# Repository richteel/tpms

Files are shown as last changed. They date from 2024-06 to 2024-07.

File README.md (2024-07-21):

# Raspberry Pi Pico Tire/Tyre Pressure Monitoring System (TPMS) Monitor

The Tire light was illuminated on the dash of my 2007 Prius. I ran around checking the air pressure in the tires. Found that a few were perhaps a little low, but not enough to cause the dash light to be lit. I then assumed that one or more of the TPMS sensors had a dead battery, but how can I know for certain? I took it to the garage and found that yes, one was dead and one had a low battery. The garage replaced them both. This got me to look and see if anyone had built a TPMS display to show the pressure and temperature of each tire.

After searching a bit, I came across an article on <a href="https://www.hackster.io/jsmsolns/arduino-tpms-tyre-pressure-display-b6e544" target="_blank">hackster.io</a> titled, "Arduino TPMS Tyre Pressure Display". It was just the thing I was looking for. I wanted to use a Raspberry Pi Pico as I have a few of them here, but the code posted does not support the RP2040 micro-controller used in the Raspberry Pi Pico. I was able to modify the code to work with the RP2040. My code will be available on GitHub at <a href="https://github.com/richteel/tpms" target="_blank">https://github.com/richteel/tpms</a> and some posts available at <a href="https://teelsys.com/" target="_blank">https://teelsys.com/</a>.

Newer cars have the details of the TPMS built in so it is not necessary to guess, but my older Prius does not. With this project, I will be able to monitor the health of my tires and when on a road trip and the dash light comes on, I don't need to panic and pull over to see if it is a major issue, that needs to be resolved right away, or if it is something that I can wait until I get to my destination.

## Items used in my build ##

- <a href="https://www.adafruit.com/product/4883" target="_blank">Raspberry Pi Pico (Pimoroni Pico Lipo) NOTE: Used Earle Philhower's core</a>
- <a href="https://www.adafruit.com/product/358" target="_blank">Adafruit 1.8" Color TFT LCD display with MicroSD Card Breakout - ST7735R</a>
- <a href="https://www.amazon.com/gp/product/B0C8RRG88V/ref=ppx_yo_dt_b_asin_title_o04_s00?ie=UTF8&psc=1" target="_blank">CC1101 Radio Frequency Transceiver Module</a>
- <a href="https://www.adafruit.com/product/160" target="_blank">Buzzer</a>
- 1 10 Ohm Resistor
- 2 150 Ohm Resistors
- <a href="https://www.pcbway.com/project/shareproject/Raspberry_Pi_Pico_Tire_Tyre_Pressure_Monitoring_System_TPMS_48b6424e.html" target="_blank">PCB from PCBWay</a>

## Code Notes ##

### TPMS_Monitor ###
The code in the TPMS_Monitor folder is the original code modified to work with the Raspberry Pi Pico code using Earle Philhower's core. This code is hard coded for US 315 MHz and Toyota PMV-107J sensors.

### TPMS_Monitor2 ###
Currently a work in progress to allow configuration to any supported sensor configuration. This code is not ready for use. Code changes will be checked in occasionally as code is updated. An Excel workbook, TPMS_Monitor2.xlsx, has been added with some analysis to help with the development of the modified version.

<hr />

I hope you enjoy this project and have success building it.

<a href="https://www.pcbway.com/project/shareproject/Raspberry_Pi_Pico_Tire_Tyre_Pressure_Monitoring_System_TPMS_48b6424e.html">PCB from PCBWay</a>

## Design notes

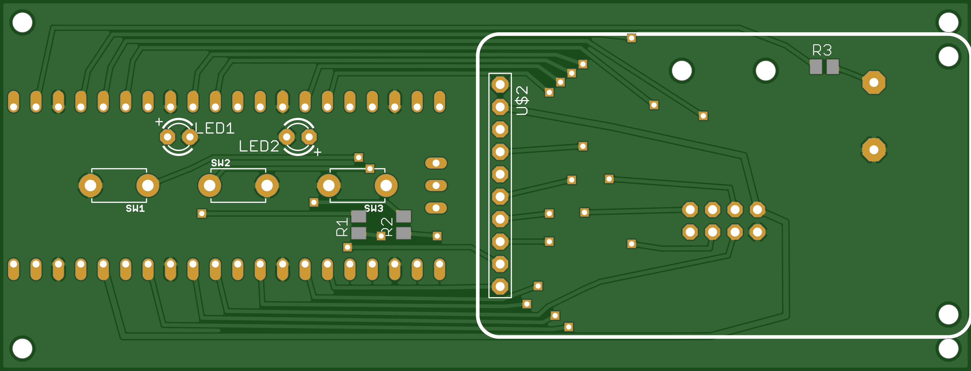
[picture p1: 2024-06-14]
PCB/top.png

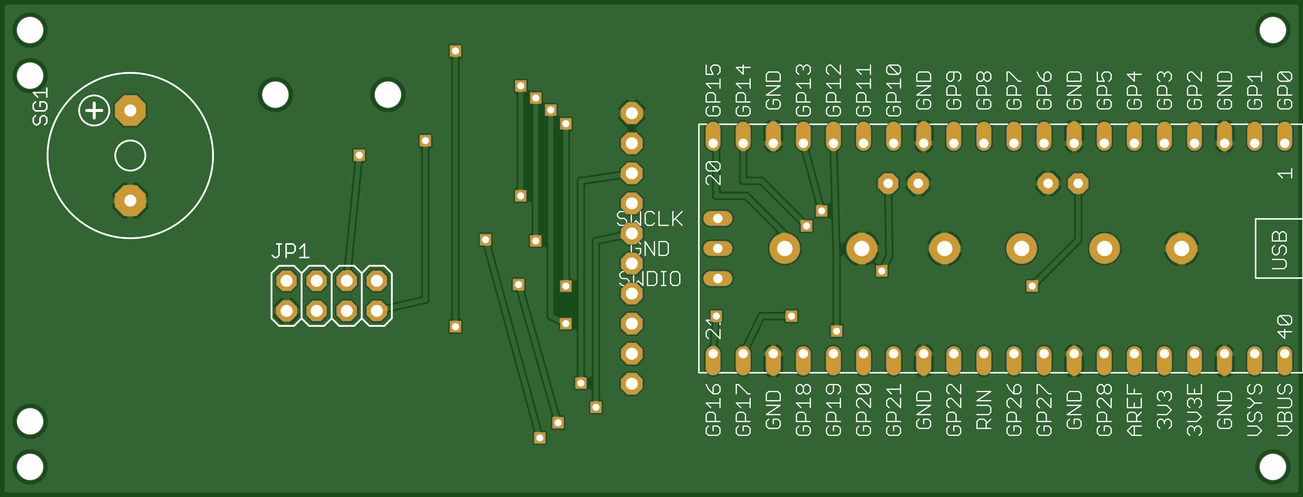
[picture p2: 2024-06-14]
PCB/bottom.png

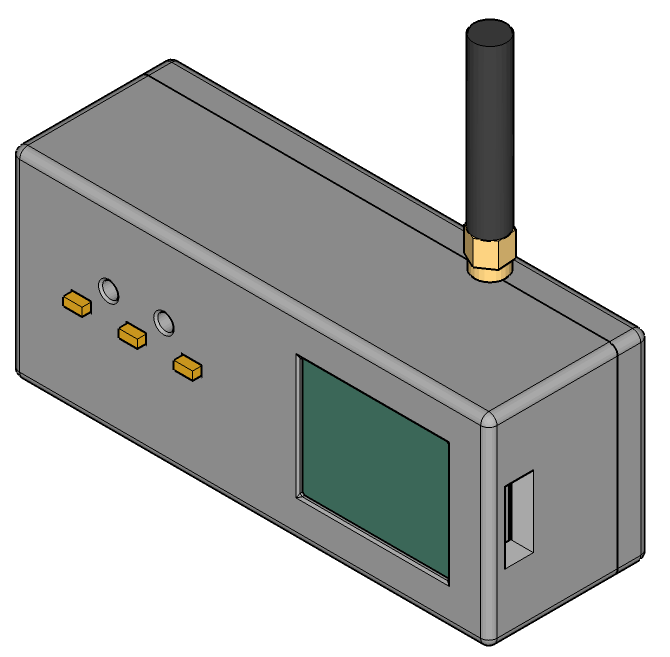
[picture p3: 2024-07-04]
Case/TPMS Case.png

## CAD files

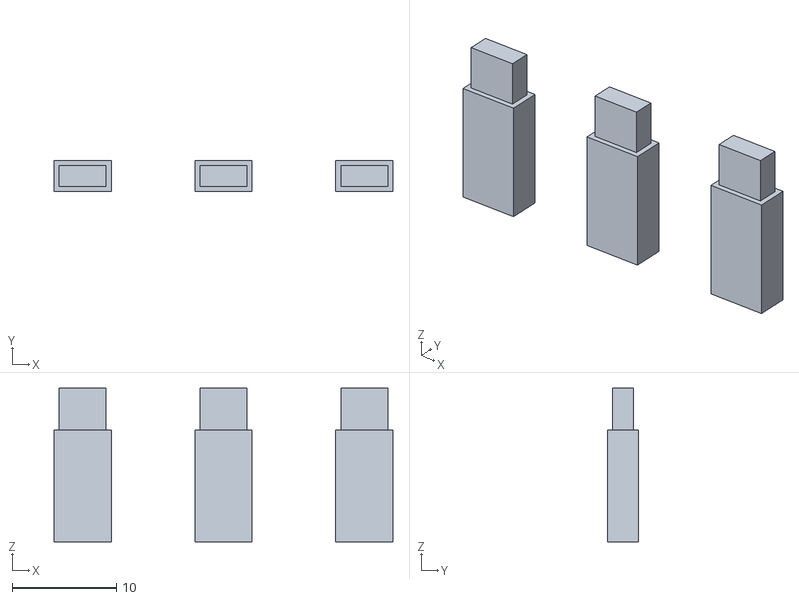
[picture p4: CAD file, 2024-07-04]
Case/TPMS Case Buttons.stl
32.5 x 3.00 x 14.7

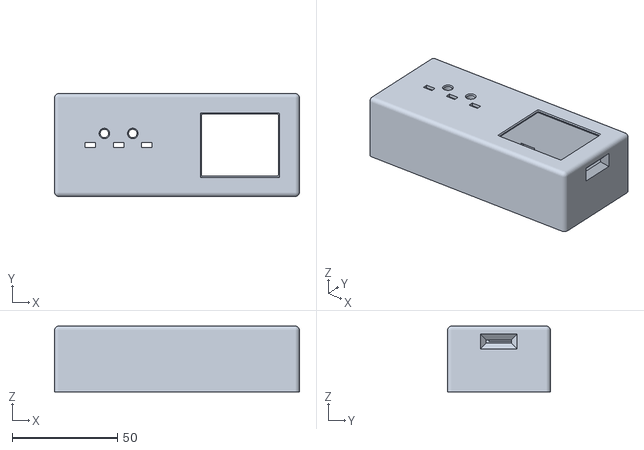
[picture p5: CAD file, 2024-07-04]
Case/TPMS Case Front.stl
116.6 x 49.0 x 31.4

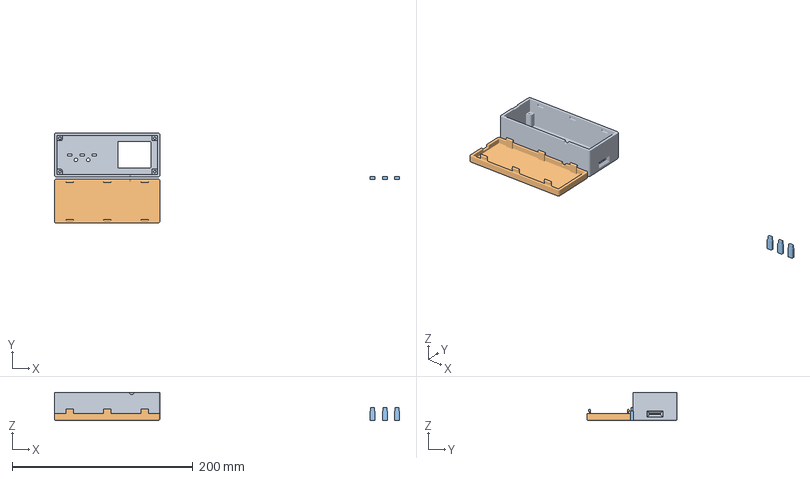
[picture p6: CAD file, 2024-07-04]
Case/TPMS Case Rear.3mf
381.8 x 100.0 x 31.4 mm
TPMS Case Front.stl
TPMS Case Rear.stl
TPMS Case Buttons.stl

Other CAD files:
Case/TPMS Case Rear.stl
Case/TPMS Case.skp

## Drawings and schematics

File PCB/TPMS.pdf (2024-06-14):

VBUS | VBUS SWCLK SWCLK | GND_P GND_P | SWDIO SWDIO

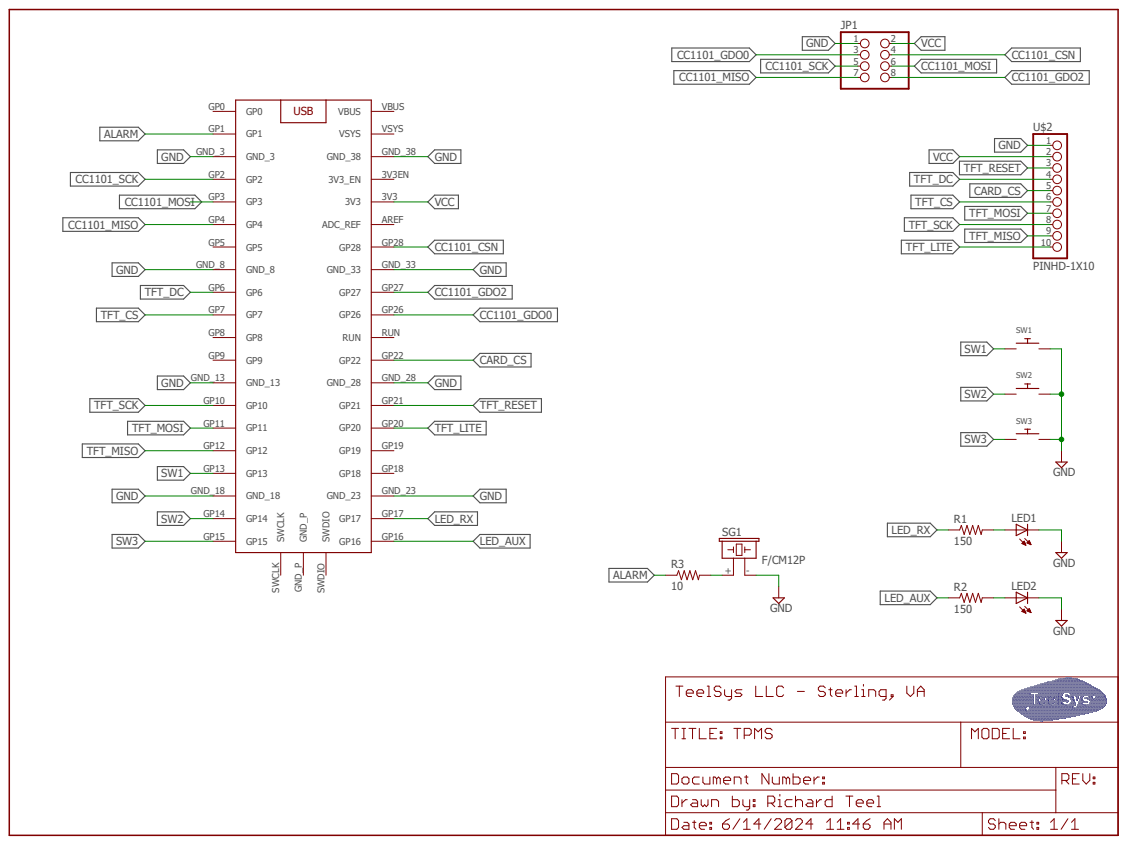
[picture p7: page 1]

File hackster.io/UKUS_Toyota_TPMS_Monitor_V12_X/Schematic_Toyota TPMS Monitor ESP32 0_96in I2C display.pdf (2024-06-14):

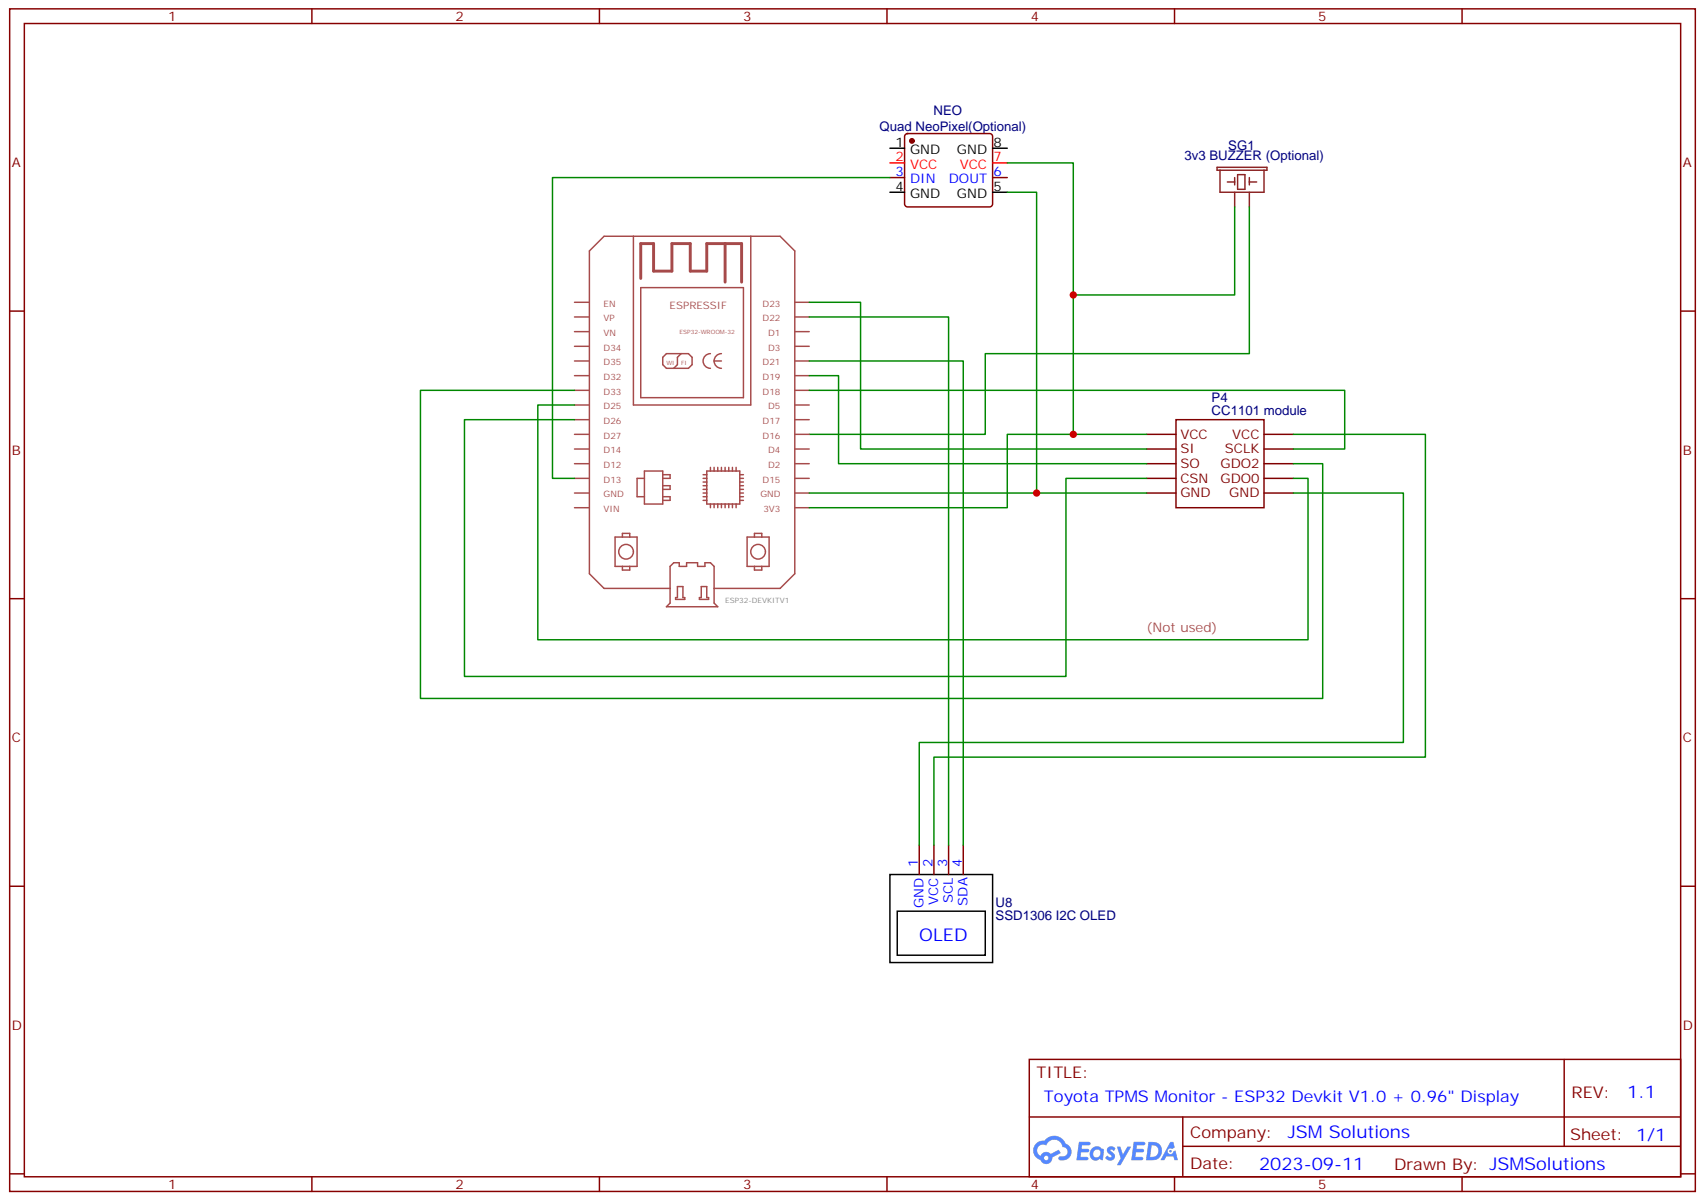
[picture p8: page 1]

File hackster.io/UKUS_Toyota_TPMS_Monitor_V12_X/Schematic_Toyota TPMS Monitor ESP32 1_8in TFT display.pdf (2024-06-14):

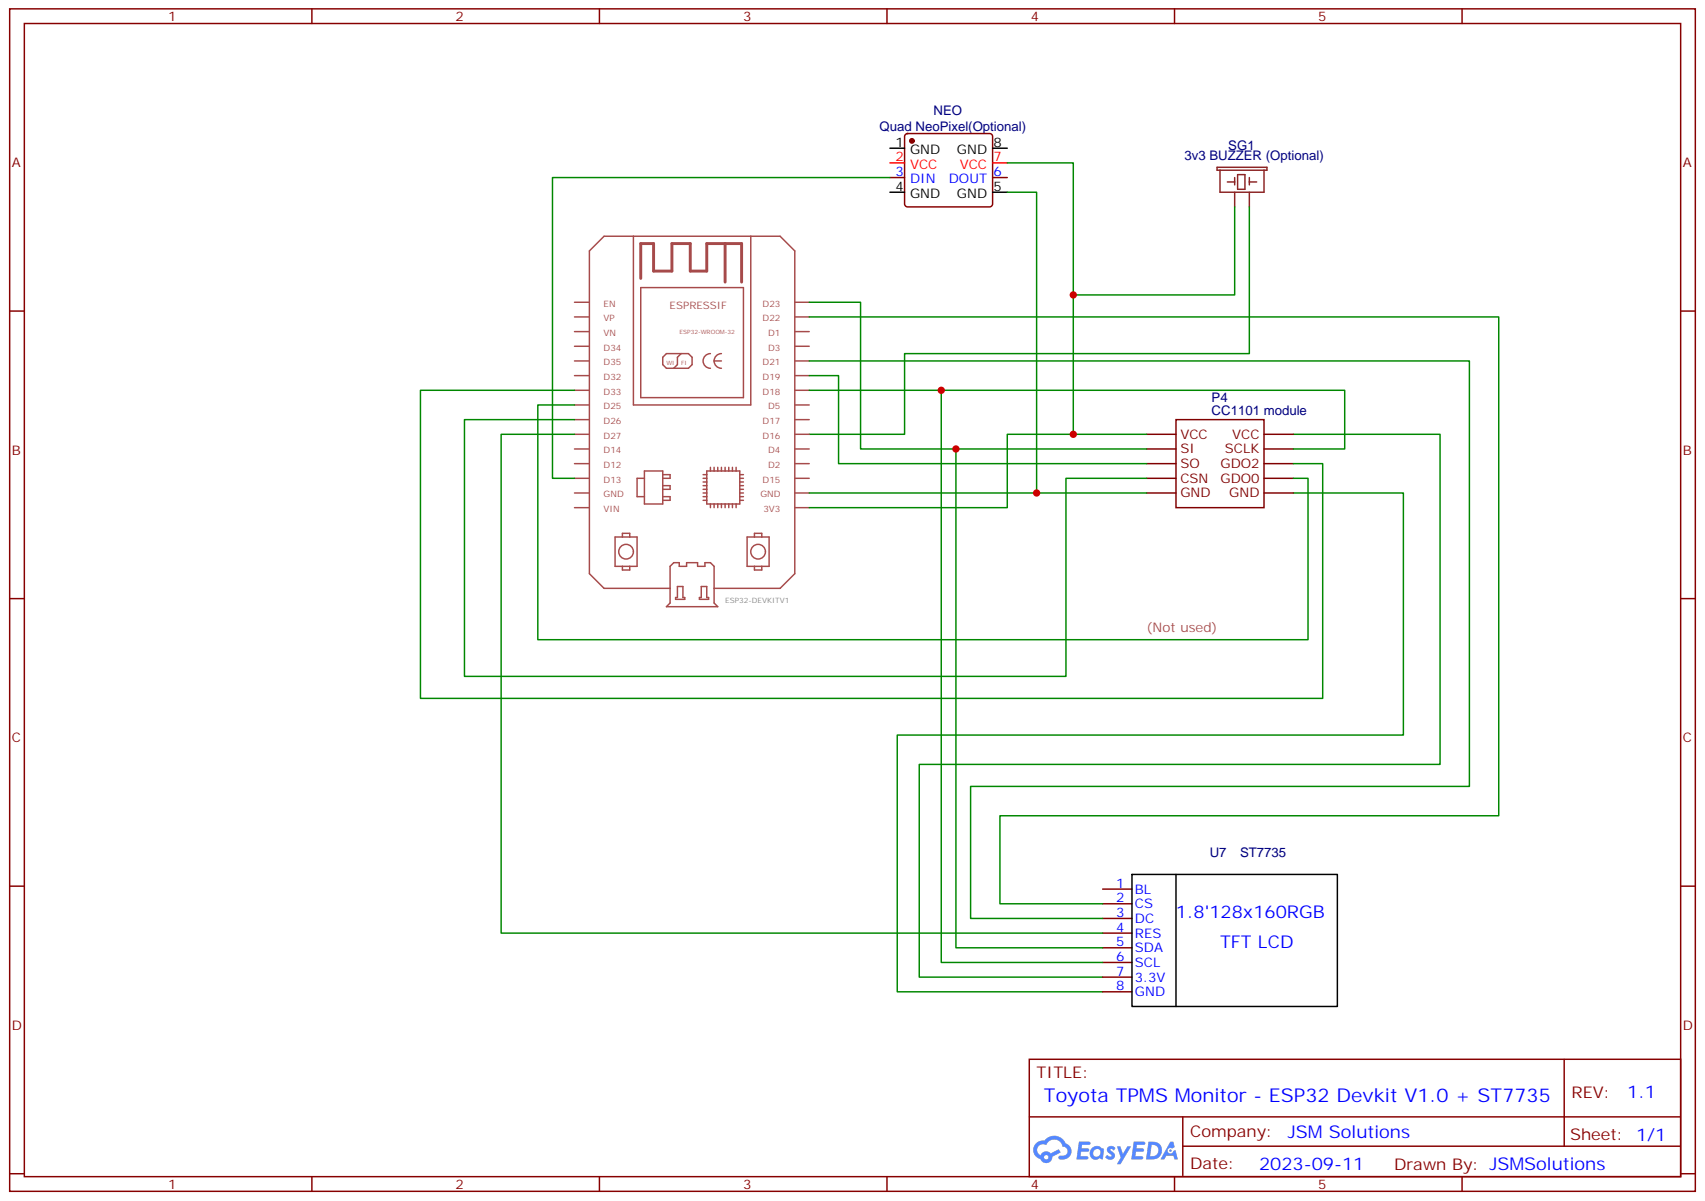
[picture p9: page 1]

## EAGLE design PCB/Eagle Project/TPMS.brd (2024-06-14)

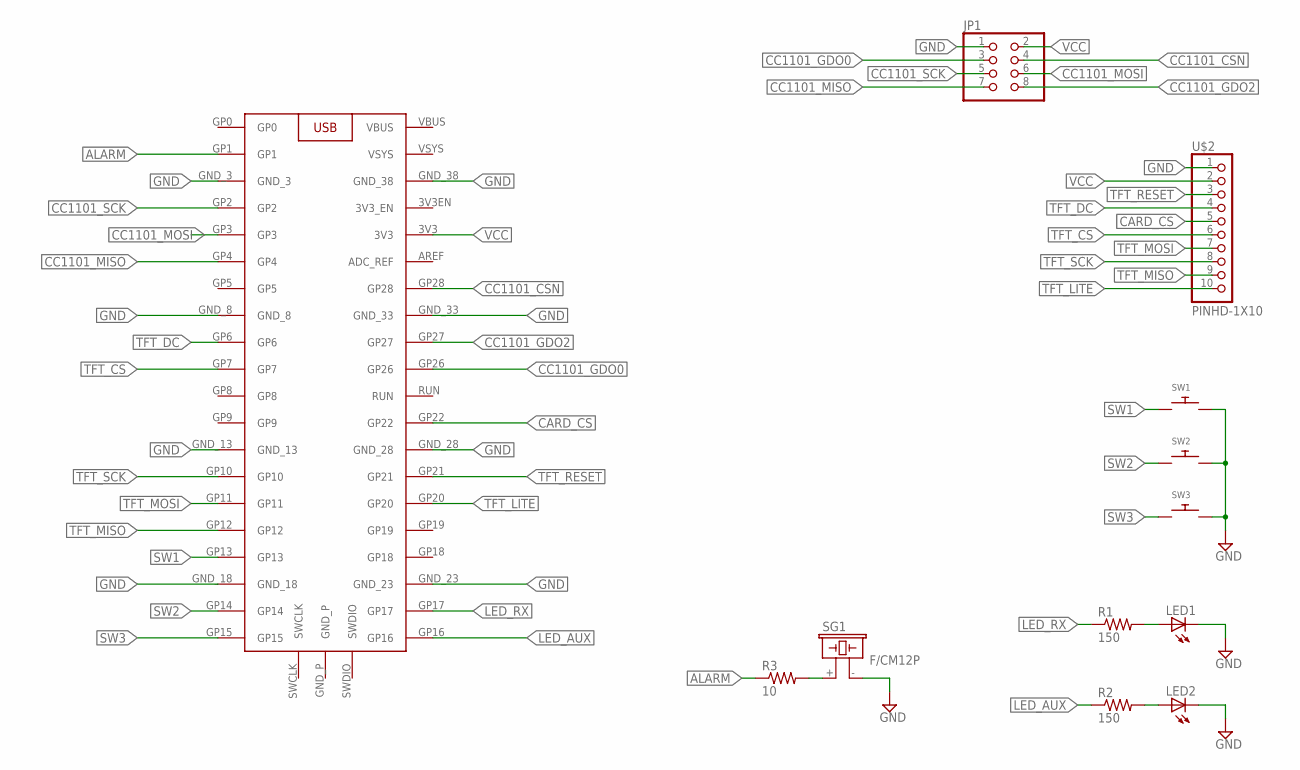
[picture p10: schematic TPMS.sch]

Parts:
JP1: PINHD-2X4; 2X04
LED1, LED2: LED3MM
R1, R2: 150; M0805
R3: 10; M0805
SG1: F/CM12P
SW1, SW2, SW3: SWITCH_PUSHBUTTONEVQ-PE; TACT_PANA-EVQ
U$1: RASPBERRY_PI_PICORASPBERRY_PI_PICO; RASPBERRY_PI_PICO
U$2: PINHD-1X10; 1X10-BIG

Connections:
ALARM: R3.1, U$1.GP1
CARD_CS: U$1.GP22, U$2.5
CC1101_CSN: JP1.4, U$1.GP28
CC1101_GDO0: JP1.3, U$1.GP26
CC1101_GDO2: JP1.8, U$1.GP27
CC1101_MISO: JP1.7, U$1.GP4
CC1101_MOSI: JP1.6, U$1.GP3
CC1101_SCK: JP1.5, U$1.GP2
GND: JP1.1, LED1.K (C), LED2.K (C), SG1.- (2), SW1.P$2, SW2.P$2, SW3.P$2, U$1.GND_3, U$1.GND_8, U$1.GND_13, U$1.GND_18, U$1.GND_23, U$1.GND_28, U$1.GND_33, U$1.GND_38, U$2.1
LED_AUX: R2.1, U$1.GP16
LED_RX: R1.1, U$1.GP17
unnamed: LED1.A, R1.2
unnamed: LED2.A, R2.2
unnamed: R3.2, SG1.+ (1)
SW1: SW1.P$1, U$1.GP13
SW2: SW2.P$1, U$1.GP14
SW3: SW3.P$1, U$1.GP15
TFT_CS: U$1.GP7, U$2.6
TFT_DC: U$1.GP6, U$2.4
TFT_LITE: U$1.GP20, U$2.10
TFT_MISO: U$1.GP12, U$2.9
TFT_MOSI: U$1.GP11, U$2.7
TFT_RESET: U$1.GP21, U$2.3
TFT_SCK: U$1.GP10, U$2.8
VCC: JP1.2, U$1.3V3, U$2.2

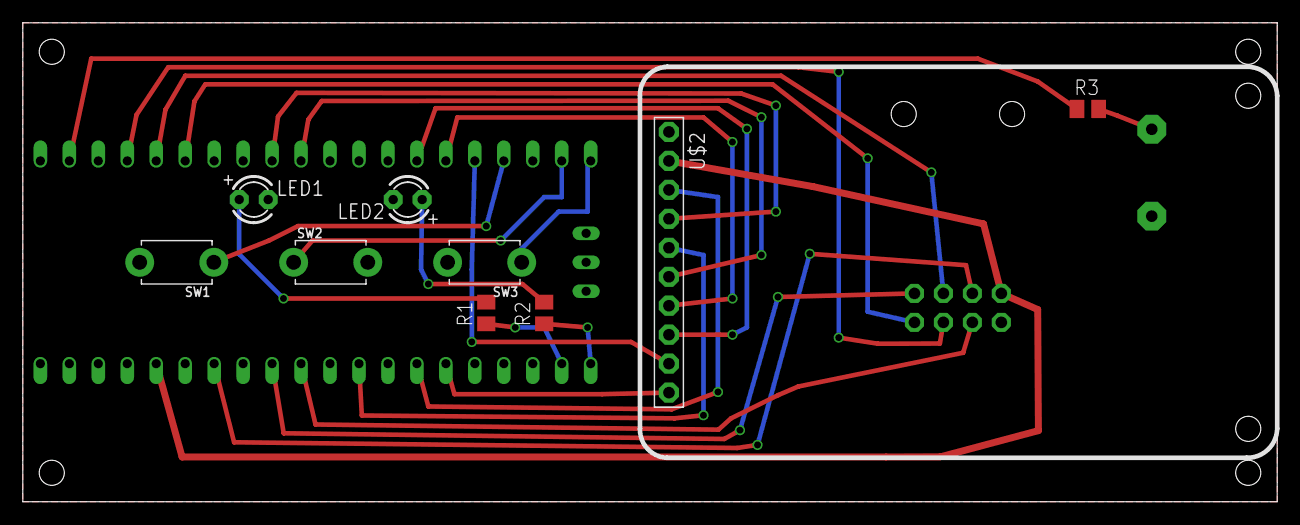
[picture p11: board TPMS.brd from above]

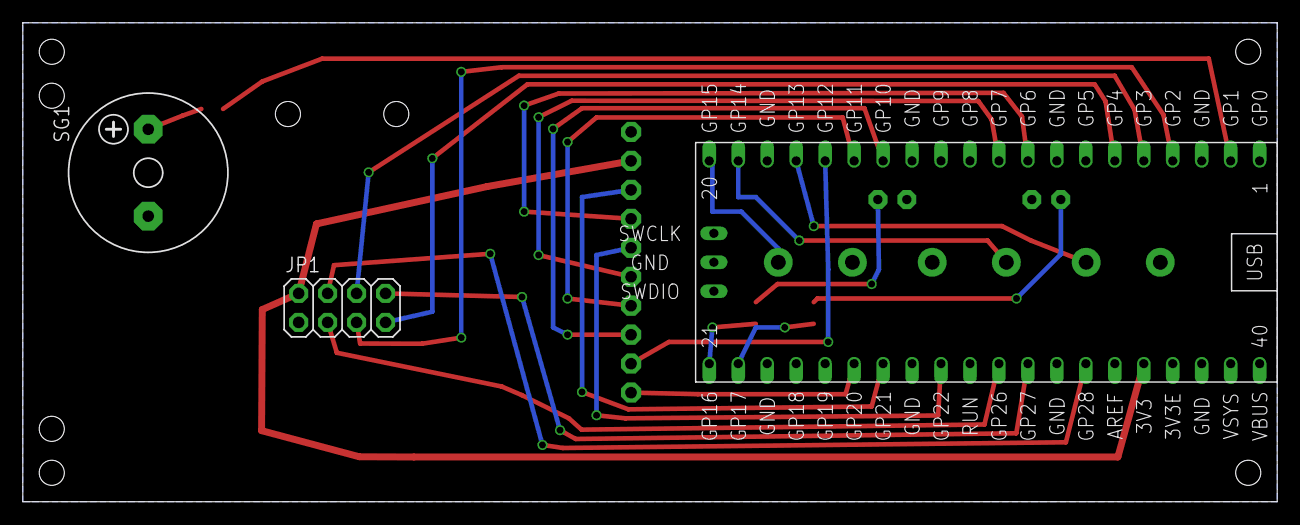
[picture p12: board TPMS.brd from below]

Board: 2 copper layers, 110.0 x 42.0 mm, 12 parts (3 on the bottom side), 25 nets.

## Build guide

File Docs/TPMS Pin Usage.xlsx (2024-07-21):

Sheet: Sheet1 (2)
CC1101 IC Pin | Pin | Function | Device | Function | Pin | Pin | Function | Device | Function | Pin | CC1101 IC Pin
 |  |  |  | GP0 | 1 | 40 | VBUS
 | + | In | Buzzer | GP1 | 2 | 39 | VSYS
 |  |  |  | GND | 3 | 38 | GND
1 | CC1101 5 | SCK | CC1101 | GP2 | 4 | 37 | 3V3_EN
20 | CC1101 6 | MOSI | CC1101 | GP3 | 5 | 36 | 3V3_Out |  |  |  |  |  |  |  |  | 1 | Black
2 | CC1101 7 | MISO | CC1101 | GP4 | 6 | 35 | ADC_VREF |  |  |  |  |  |  |  |  | 2 | Red
 |  |  |  | GP5 | 7 | 34 | GP28/A2 | CC1101 | CS/SS | CSN (4) |  |  |  |  |  | 3 | White
 |  |  |  | GND | 8 | 33 | GND |  |  |  |  |  |  |  |  | 4 | Violet
 | 4 | D/C | LCD/SD Card | GP6 | 9 | 32 | GP27/A1 | CC1101 | RX | GDO2 (8) |  |  |  |  |  | 5 | Orange
 | 6 | TFT_CS | LCD | GP7 | 10 | 31 | GP26/A0 | CC1101 | CD | GDO0 (3) |  |  |  |  |  | 6 | Green
 |  |  |  | GP8 | 11 | 30 | RUN |  |  |  |  |  |  |  |  | 7 | Yellow
 |  |  |  | GP9 | 12 | 29 | GP22 | SD Card | Card_CS | 5 |  |  |  |  |  | 8 | Brown
 |  |  |  | GND | 13 | 28 | GND
 | LCD 8 | SCK | LCD/SD Card | GP10 | 14 | 27 | GP21 | LCD/SD Card | Reset | 3
 | LCD 7 | MOSI | LCD/SD Card | GP11 | 15 | 26 | GP20 | LCD | LITE | 10
 | LCD 9 | MISO | LCD/SD Card | GP12 | 16 | 25 | GP19
7 | GND | Back | Switch | GP13 | 17 | 24 | GP18
 |  |  |  | GND | 18 | 23 | GND
6 | GND | Select | Switch | GP14 | 19 | 22 | GP17 | LED | RX | +
3 | GND | Next | Switch | GP15 | 20 | 21 | GP16 | LED | Aux | +
 |  |  |  |  |  |  |  |  |  |  |  | LCD Pins | Function | Pico Pin | Pico Function
 |  |  |  |  |  |  | GP25 | Pico | LED | DEBUGPIN |  | 1 | GND
 |  |  |  |  |  |  |  |  |  |  |  | 2 | VCC
Highlight Device | Switch |  |  |  |  |  |  |  |  |  |  | 3 | RESET | 27 | SP21
 |  |  |  |  |  |  |  |  |  |  |  | 4 | D/C | 9 | GP6
 |  |  |  |  |  |  |  |  |  |  |  | 5 | CARD_CS | 29 | GP22
 |  |  |  |  |  |  |  |  |  |  |  | 6 | TFT_CS | 10 | GP7
 |  |  |  |  |  |  |  |  |  |  |  | 7 | MOSI | 5 | GP3
 |  |  |  |  |  |  |  |  |  |  |  | 8 | SCK | 4 | GP2
 |  |  |  |  |  |  |  |  |  |  |  | 9 | MISO | 6 | GP4
 |  |  |  |  |  |  |  |  |  |  |  | 10 | LITE | 26 | GP20

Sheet: REF
Devices
-None-
Buzzer
CC1101
LCD
LED
SD Card
Switch

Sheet: Sheet2
Pos: ID: | 171 | 234.5 | Pos: ID: | 171 | 171
3A3515A | 39 |  | Counter: 1 | 57
5555262 | 45 |  | Counter: 2 | 61
D97C8E3 | 44 |  | Counter: 3 | 53
E90614A | 43 |  | Counter: 0
 |  |  | Counter: 4
Pos: ID: | PSI | Position
3A3515A | 31.6 | LR
5555262 | 31.9 | RF
D97C8E3 | 32.7 | LF
E90614A | 27.9 | RR

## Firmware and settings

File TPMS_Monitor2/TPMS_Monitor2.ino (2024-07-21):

#define VERSION "0.1"

/*****************************************************************************
 *                              FreeRTOS Setup                               *
 *****************************************************************************/
#if !defined(ESP_PLATFORM) && !defined(ARDUINO_ARCH_MBED_RP2040) && !defined(ARDUINO_ARCH_RP2040)
#pragma message("Unsupported platform")
#endif

// ESP32:
#if defined(ESP_PLATFORM)
TaskHandle_t task_loop1;
void esploop1(void *pvParameters) {
  setup1();

  for (;;)
    loop1();
}
#endif

#if defined(ARDUINO_ARCH_MBED_RP2040) || defined(ARDUINO_ARCH_RP2040)
#include <FreeRTOS.h>
#include <task.h>
#include <semphr.h>
#define xPortGetCoreID get_core_num
#endif

/*****************************************************************************
 *                               Include Files                               *
 *****************************************************************************/
#include <Dictionary.h>
#include <SPI.h>

/*****************************************************************************
 *                               Project Files                               *
 *****************************************************************************/
#include "pcb.h"
#include "StructsAndEnums.h"
#include "globals.h"
#include "DebugLogging.h"
#include "cc1101.h"

#if USE_DISPLAY == DISPLAY_2_INCH_ST7735_DISPLAY
#include "display_128x160.h"
#endif

// For debugging should be removed
#include "types.h"


/*****************************************************************************
 *                                  GLOBALS                                  *
 *****************************************************************************/



/*****************************************************************************
 *                                 LOG FILES                                 *
 *****************************************************************************/
char logDebug[] = "/logs/debug.log";
char logDebugArchive[] = "/logs/debug_1.log";

/*****************************************************************************
 *                                DEBUG LEVEL                                *
 *****************************************************************************/
DebugLevels debugLevel = DebugLevels::Verbose;
// DebugLevels debugLevel = DebugLevels::Info;
// DebugLevels debugLevel = DebugLevels::Warning;
// DebugLevels debugLevel = DebugLevels::Error;

int waitLoopsToPrintTaskInfo = 100;

/*****************************************************************************
 *                                   QUEUES                                  *
 *****************************************************************************/
static const uint8_t log_queue_len = 10;
static QueueHandle_t log_queue;

static const uint8_t remote_queue_len = 5;
static QueueHandle_t remote_queue;

/*****************************************************************************
 *                                   MUTEX                                   *
 *****************************************************************************/
static SemaphoreHandle_t sdcard_mutex;
static SemaphoreHandle_t rtc_mutex;

/*****************************************************************************
 *                               INO FUNCTIONS                               *
 *****************************************************************************/
void init_display() {
  switch (USE_DISPLAY) {
    case DISPLAY_1_INCH_YB_I2C_DISPLAY_ADAFRUIT:
      // if (!display.begin(SSD1306_EXTERNALVCC, I2C_ADDRESS)) {
      //   SER.println(F("SSD1306 allocation failed"));
      //   while(1)
      //   {
      //     delay(10);// Don't proceed, loop forever
      //   }
      // }
      // display.clearDisplay();
      // display.display();
      // SER.println(F("Adafruit SSD1306 initialised OK"));
      SER.println(F("ERROR: Adafruit SSD1306 Not Implemented"));
      break;
    case DISPLAY_1_INCH_YB_I2C_DISPLAY:
      // Wire.begin();
      // Wire.setClock(400000L);
      // display.begin(&Adafruit128x64, I2C_ADDRESS);
      // display.setFont(Adafruit5x7);
      // display.clear();
      // ShowTitle();
      // SER.println(F("SSD1306 initialised OK"));
      SER.println(F("ERROR: Generic SSD1306 Not Implemented"));
      break;
    default:
#if defined(LCD_SPI)
      ScreenSetup();
#else
#error Display not found in intialization setion of Setup()
#endif
      break;
  }
}

void init_hardware() {
  // Setup SPI
  CC1101_SPI.setSCK(CC1101_SCK);
  CC1101_SPI.setMOSI(CC1101_MOSI);
  CC1101_SPI.setMISO(CC1101_MISO);
  CC1101_SPI.begin();

#if defined(LCD_SPI)
  if (&LCD_SPI != &CC1101_SPI) {
    LCD_SPI.setSCK(LCD_SCK);
    LCD_SPI.setMOSI(LCD_MOSI);
    LCD_SPI.setMISO(LCD_MISO);
    LCD_SPI.begin();

    delay(2000);
  }
#endif

// Setup hardware
/**** CC1101 ****/
#ifdef CC1101_CD
  pinMode(CC1101_CD, INPUT);
#endif
  pinMode(CC1101_RX, INPUT);
  pinMode(CC1101_CS, OUTPUT);

  digitalWrite(CC1101_CS, HIGH);

/**** LCD/SD CARD ****/
#ifdef LCD_LITE
  pinMode(LCD_LITE, OUTPUT);
  digitalWrite(LCD_LITE, HIGH);
#endif

/**** LEDS ****/
#ifdef LED_DEFAULT
  pinMode(LED_DEFAULT, OUTPUT);
  digitalWrite(LED_DEFAULT, !ACTIVE_LED);
#endif
#ifdef LED_RX
  pinMode(LED_RX, OUTPUT);
  digitalWrite(LED_RX, !ACTIVE_LED);
#endif
#ifdef LED_AUX
  pinMode(LED_AUX, OUTPUT);
  digitalWrite(LED_AUX, !ACTIVE_LED);
#endif
#ifdef LED_DBUG
  pinMode(LED_DBUG, OUTPUT);
  digitalWrite(LED_DBUG, !ACTIVE_LED);
#endif

/**** BUZZER ****/
#ifdef BUZZER
  pinMode(BUZZER, OUTPUT);
  digitalWrite(BUZZER, !ACTIVE_BUZZER);
#endif

/**** SWICHES ****/
#ifdef SW_BACK
#if ACTIVE_SW == LOW
  pinMode(SW_BACK, INPUT_PULLUP);
#else
  pinMode(SW_BACK, INPUT);
#endif
#endif
#ifdef SW_SELECT
#if ACTIVE_SW == LOW
  pinMode(SW_SELECT, INPUT_PULLUP);
#else
  pinMode(SW_SELECT, INPUT);
#endif
#endif
#ifdef SW_NEXT
#if ACTIVE_SW == LOW
  pinMode(SW_NEXT, INPUT_PULLUP);
#else
  pinMode(SW_NEXT, INPUT);
#endif
#endif
}

void init_serial() {
#ifdef SER
  long intervalSerial = 7000;
  unsigned long previousMillisSerial = millis();
  SER.begin(115200);

  // Wait for the serial port to connect
  while (!SER && ((millis() - previousMillisSerial) < intervalSerial)) {
    delay(1);  // wait for serial port to connect.
  }

  // Print 5 blank lines on startup
  for (int i = 0; i < 5; i++) {
    SER.println("");
  }
  delay(500);
#endif
}



/*****************************************************************************
 *                                   TASKS                                   *
 *****************************************************************************/



/*****************************************************************************
 *                                   SETUP                                   *
 *****************************************************************************/
void setup() {
  init_serial();

  init_hardware();

  init_globals();

  if (unitSettings.alarmEnabled) {
    digitalWrite(BUZZER, ACTIVE_BUZZER);  //audible alarm test
    delay(200);
    digitalWrite(BUZZER, !ACTIVE_BUZZER);
    delay(300);
    digitalWrite(BUZZER, ACTIVE_BUZZER);  //audible alarm test
    delay(200);
    digitalWrite(BUZZER, !ACTIVE_BUZZER);
    delay(500);
  }

#ifdef SER
  SER.println(F("########################################################################"));
  SER.println(F(""));
  SER.println(F("STARTING..."));
  SER.print(F("Software version "));
  SER.println(VERSION);
  SER.print(F("Hardware version "));
  SER.printf("%d.%d\n", PCB_VERSION_MAJ, PCB_VERSION_MIN);
  SER.print(F("Processor: "));
  SER.println(PROC_TYPE);
#else
#define SER Serial
#endif

  init_display();

  //initialise the CC1101

  SER.print(F("Resetting CC1101 "));
  uint8_t retrycount = 0;
  while (retrycount < 5) {
    SER.print(F("."));
    CC1101_reset();
    if (readConfigReg(0) == 0x29)
      break;
    retrycount++;
    delay(5);
  }
  SER.println(F(""));

  if (readConfigReg(0) == 0x29) {
    SER.println(F("CC1101 reset successful"));
  } else {
    SER.println(F("CC1101 reset failed. Try rebooting"));
#ifdef USE_LCDDISPLAY
#ifdef USE_2_INCH_ST7735_DISPLAY
    DisplayWarning((char *)"CC1101 reset failed", 0, 64);
    DisplayWarning((char *)"Power off/on", 0, 80);
    while (1) {
      delay(10);  // Don't proceed, loop forever
    }
#endif
#endif
  }


  cc1101_init_vars();
  ConfigureCC1101();
  SER.print(F("CC1101 configured for "));
  if(carSettings.freq == TPMS_Frequencies::US_315MHz) {
     SER.print (F("US (315MHz)"));
  } else {
     SER.print (F("UK (433MHz)"));
  }
  SER.printf(" and %s sensor\n", tpmsSensorName[carSettings.tpmsSensorType]);

  //
}

/*****************************************************************************
 *                                    LOOP                                   *
 *****************************************************************************/
long intervalSerial = 1000;
unsigned long previousMillisSerial = millis();

void loop() {

  if (SER && ((millis() - previousMillisSerial) >= intervalSerial)) {
    digitalWrite(LED_AUX, !digitalRead(LED_AUX));
    previousMillisSerial = millis();
  }
}

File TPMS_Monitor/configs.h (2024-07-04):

//Select the display type being used:
// #define USE_1_INCH_YB_I2C_DISPLAY 1
#define USE_2_INCH_ST7735_DISPLAY 1
//#define USE_2_INCH_ST7789_DISPLAY 1  //(round display)
//#define USE_24_INCH_ILI9341_DISPLAY 1


//Receive frequency
// #define UK_433MHz 1
#define US_315MHz 1

//Vehicle/sensor type
//#define Toyota_TRW_C070 1
//#define Toyota_PMV_C210 1   //Toyota Auris, should also work for PMV-C010?? and PMV-C215 (Toyota Corolla)
//#define Hyundai_i35 1  //uses PMV-C210 sensor
//#define Schrader_C1100 1  //used on Hyundai Tucson TL/TLE 01/2015-12/2015
//#define Schrader_A9054100 1
#define Toyota_PMV_107J 1   //used on Lexus RX series 07/2013-09/2015
//#define Renault 1
//#define Zoe 1   //for Renault Zoe 09/2012 to 06/2019 only (you must select 'Renault' define as well for this!)
//#define Dacia 1
//#define NissanLeaf 1
//#define Citroen 1
//#define PontiacG82009 1
//#define TruckSolar 1
//#define JansiteSolar 1 
//#define Subaru 1
// #define Mercedes_AMG_GT 1


//#define Ford 1

//Possible Ford variants..
//#define Ford_FSeries_SD 1
//#define Ford_FSeries_2006_2008 1
//#define Ford_ESeries_TEST 1
//#define Ford_OtherVariants 1



//#define Jansite 1  //requires bigger buffer sizes - won't work on ProMicro or Nano?
 


#ifdef Ford_FSeries_SD
   #define FordType 2
#elif Ford_FSeries_2006_2008
   #define FordType 1
#elif Ford_ESeries_TEST
   #define FordType 3
#else
   #define FordType 0
#endif



////#define INCLUDESPARETYRE 1    - nolonger used. If no spare with TPMS, just set the ID to 0xFFFFFFF
//#define INCLUDE_WINTER_SET 1

//Pressure display and limits units (default is PSI and deg C if these not set)
//#define DISPLAY_PRESSURE_AS_BAR 1
//#define DISPLAY_PRESSURE_AS_KPA 1
//#define DISPLAY_TEMP_AS_FAHRENHEIT 1  //if uncommented,temperature is displayed as deg F, otherwise displayed as deg C

#define ENABLE_PRESSURE_ALARMS 1
#define ENABLE_TEMPERATURE_ALARMS 1

#define ENABLE_AUDIBLE_ALARM 1

#define ENABLE_PRESSURE_ALARM_TEMPERATURE_COMPENSATION 1


#if defined(USE_2_INCH_ST7735_DISPLAY) || defined(USE_2_INCH_ST7789_DISPLAY) || defined(USE_1_INCH_YB_I2C_DISPLAY)  || defined(USE_24_INCH_ILI9341_DISPLAY)
   #define USE_LCDDISPLAY 1
#endif

//config checks...

#if defined(UK_433MHz) && defined(US_315MHz)
   #error Cannot define both 433MHz and 315MHz simultaneously
#endif

#if !defined(UK_433MHz) && !defined(US_315MHz)
   #error Must define either 433MHz or 315MHz
#endif


#if defined(USE_LCDDISPLAY) && (defined(USE_2_INCH_ST7735_DISPLAY) || defined(USE_2_INCH_ST7789_DISPLAY)  || defined(USE_24_INCH_ILI9341_DISPLAY)) && defined(ARDUINO_AVR_PROMICRO)
   #error ProMicro does not have enough memory for this display!
#endif

//tyre IDs for vehicle....(may need to prefix known IDs with leading 'F' to match reception)
  // #define FRONT_LEFT  0x01721EB0L
  // #define FRONT_RIGHT 0x0172221FL
  // #define REAR_LEFT   0x0172223EL
  // #define REAR_RIGHT  0x01721E9AL
  #define WINTER_FRONT_LEFT  0x02721EB0L
  #define WINTER_FRONT_RIGHT 0x0272221FL
  #define WINTER_REAR_LEFT   0x0272223EL
  #define WINTER_REAR_RIGHT  0x02721E9AL
  #define WINTER_SPARE       0x0FFFFFFFL
  // Test (2007 Prius)
  #define FRONT_LEFT  0x0D97C8E3L 
  #define FRONT_RIGHT 0x05555262L 
  #define REAR_LEFT   0x03A3515AL
  #define REAR_RIGHT  0x0E90614AL
  // #define SPARE       0x03EF5BF0L
  #define SPARE       0x0L
  
  // #define FRONT_LEFT  0x0L 
  // #define FRONT_RIGHT 0x0L 
  // #define REAR_LEFT   0x0L
  // #define REAR_RIGHT  0x0L




int Ford_SensorType = FordType;  //3 different types seen, select 0,1,2 to match the pressure readings


//Settings for pressure and temperature limits (including Winter tyres if required). Used as flashing warnings on display and audible alarm if enabled in hardware
const float PressureLimitsTemperature = 20;
const  double PressureLowLimits[]
{
  33, 33, 
  31, 31,
  30
  #ifdef INCLUDE_WINTER_SET
    , 30, 30, 
    30, 30,
    30
  #endif
};

const double  PressureHighLimits[]
{
  37, 37, 
  35, 35,
  33
  #ifdef INCLUDE_WINTER_SET
    , 33, 33, 
    33, 33,
    33
  #endif
};

//set temperature limits to Fahrenheit or Centigrade depending on DISPLAY_TEMP_AS_FAHRENHEIT setting (will be converted to centigrade when loading if required)
const float  TemperatureLowLimits[]
{
  -10, -10, 
  -10, -10,
  -10
  #ifdef INCLUDE_WINTER_SET
    , -20, -20, 
    -20, -20,
    -20
  #endif
};

const float  TemperatureHighLimits[]
{
  33, 33, 
  33, 33,
  33
  #ifdef INCLUDE_WINTER_SET
    , 33, 33, 
    33, 33,
    33
  #endif
};

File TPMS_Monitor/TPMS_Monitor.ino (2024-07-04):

//Changes:
//V1.0 - Originally published version
//V2.0 - Altered to allow support for spare tyre reporting (although not displayed on LCD display)
//V3.0 - Added #define in globals.h to switch between BAR and PSI
//V4.0 - Now uses synchronous data from CC1101 and option of using either the SPI or the hardware pin for the CD signal (#define USE_HW_CD in globals.h). Also tideied up debug information if required (globals.h #defines)
//V5.0 - Corrected possible sync error when looking for start of data stream. Fix should improve hit rate on valid TPMS detection
//V5.1 - Added freq offset updates (SWRA159) - removed again(makes it worse!)
//V5.1.1 - Added functions for extracting RSSI as dbm
//V6.0 - Added code for options for US (315MHz) or UK (433MHz), also for different sensor types (PMV-C210, PMV-107J)
//V6.1 - Added support for Seeeduino Xiao
//V6.2 - Included support for Renault (Renault Clio, Renault Captur and maybe Dacia Sandero?) as an option (to be verified)
//V6.3 - Included support for Citroen (possibly also includes Peugeot and likely Fiat, Mitsubishi, VDO-types) as an option (to be verified)
//V6.4 - Some code rationalisation, all sensor timings now in Configs.h
//V6.5 - Tried to improve PMV-107J decode by starting at the end of the buffer and working forwards
//V6.6 - Added other car types (under development), changed PMV-107J frequency deviation, added #define as option to only detect specified IDs, stripped leading 4 bits from ID (as per 'Glopes' comment) for Toyota, moved some globals settings to Config.h, changed AGC settings 
//V6.7 - Adjusted PMV_C210 presure calculation to lower PSI by 0.3 (as suggested by Steven Andrews by comparing with Autel programmer). 
//     - Added option for displaying Fahrenheit (#ifdef DISPLAY_TEMP_AS_FAHRENHEIT in configs.h) rather than centigrade.
//     - Re-introduced flashing display if pressures outside of pre-set limits (enabled by #define ENABLE_PRESSURE_ALARMS in configs.h. PressureLowLimits and PressureHighLimits in config.h should be set as required)
//V7.0 - Included option for 1.8" TFT display (requires Seeeduino Xiao for extra memory)
//V8.0 - Added optional audible alarm for pressure alarms. Improved display flashing. Tested with Nissan Leaf 433MHz OK
//V9.0 - Added Pontiac (US) decoder option, moved all CC1101 configs to sensor-spcific include files, improved timer handling. Added temperature compensation for pressure limits (set pressure limits reference temperature in configs.h). Added kPA pressure display option.
//       Pressures always stored locally as psi and temperatures as deg C - including limits (converted if required for the display).
//       Tyre pressure and temperature limits are assumed to be in the required units e.g. bar, kpa, psi, degC, degF depending on config choice.
//       Added support for 240x240 round display (Steven Andrews' display code)
//V9.1 - Added provisional support for Arduino Nano 33 IOT board
//V9.2 - Fixed bugs in audible alarm for temperatures.. Fixed missing F/C for round display.
//V9.3 - Corrected some title positioning for display.h, Added support for Renault Zoe (pre 07/2019)
//V9.4 - Corrected compile error when not using display - thanks Zaran on Hackster.io
//V9.5 - Changes to cope with multiple tyre sets (Summer/Winter). Corrected bug in ID matching (IDs were allocated to PROGMEM but referenced as SRAM for lookups), this meant tyre position was not being reported correctly. Moved Ref[3] to globals.
//V9.6 - Fixed bug where lcd display was partially obliterated if TYRECOUNT > 4 (the default is now 5)
//V9.7 - Fixed bug in Ford.h which caused out of range temperture values to be displayed on screen when temperture below 0C. 
//       Changes to support new larger screen type (supplied by Steven Andrews' - thank you!). 2.4inch LCD Display Module 65K RGB Colors, ILI9341 2.4" TFT 240×320. Requires Adafruit ILI9341 library.
//V9.8 - Added support for Truck Solar TPMS and Mega256 build
//V9.9 - Added support for Ford strange Ford E-series (Tom Logan). It appears temperature format is reported in 2 ways depending upon whether or not the sensor was manually triggered (or not)
//V10.0 - Improved Ford incoming message handling
//V10.1 - Changed Ford pressure decode in line with actual E-series Schrader sensor feedback. This sensor also seems to delay sending temperatures after sleeping and sends a counter instead.
//V10.2 - Missing conditional for 2.4" screen in setup in .ino file (line 350) preventing initialisation of display (USE_24_INCH_ILI9341_DISPLAY). Causes screen to continually display white.
//V10.3 - Changed PMV-107J & PMV-C210 to try to improve detections. Code now walks through the received bit stream until a valid checksum match is found (or runs out of data)
//        This avoids the need to look for sync bits which may not be reliable at the start of the bit stream (includes change to common.h)
//V10.4 - Added trial for Toyota Sienna (TRW C070 sensor)
//V10.5 - Improvements to Toyota Sienna TRW C070 detection/validation. Added Hyundai I35 as option for this same sensor. 
//        Fixed temperature display bug (thanks Larry on Hackster for pointing this out.) - it would overflow/underflow with certain readings
//        Feedback from Alistair Clark on Hackster indicates that the C210 decode also works for Toyota Corolla (2019-22 PMV-C215 sensor)
//V10.6 - Corrected slight bug in display.h for Hyundai (should have been newline print)/ Thanks to grigata on Hackster for pointing this out.
//        Reported by gamer765 that PMV-107J also works for PMV-C11A sensors.
//        Added support for Hyundai Tucson TL/TLE (2015) using Schrader C1100/C8000 sensor. Many thanks to RM for helping on this one.
//V10.7 - Correct bug in CC1101.h in ReadFIFO function - it was missing the return statement (but worked for Xiao without it???)! Thanks to Nomake Wan for helping out on this one.
//        Added possible support for Xiao RP2040 (TBC)
//        Added support for Schrader A0009054100 senosr used on Smart Fortwo 01/2007-02/2014 (433MHz) - OOK
//V10.8 - Debugged to get Xiao RP2040 working. Same schematic as previous Xiao
//V11.0 - Added Winter tyre pressure limits (optionally). These could be easily be missed and cause an indexing outside of the array if INCLUDE_WINTER_SET enabled.
//        Added suport for Summer/Winter tyres on the displays (previously only available on serial output). Basically, if so configured, the
//        Summer and Winter tyre IDs will be recognised and displayed in their position on the display - user should make sure the other tyre set is out of range!
//V11.1 - Abandonded (not published)
//V11.2 - Changed handling of CD in main routine. Need to configure a valid ENDTIMING_MAX for each sensor type. This is used to exit the CD loop early if a reasonable number of bits have been received and it's been > ENDTIMING_MAX since the last edge (i.e. an ivalid bit timing - probably only valid for Manchester coded data)
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

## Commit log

2024-06-14 Added PCB files and initial code working with Raspberry Pi Pico and TPMS for Toyota PMV-107J.
    [TPMS.brd, TPMS.sch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]
2024-07-04 Added case files and changed code for my odd display.
    [TPMS Case Buttons.stl, TPMS Case Front.stl, TPMS Case Rear.3mf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]
2024-07-21 TPMS-1 Updated README.md, added TPMS_Monitor2 code, and test Jira integration.
    [TPMS Pin Usage.xlsx, TPMS_Monitor2.xlsx]
